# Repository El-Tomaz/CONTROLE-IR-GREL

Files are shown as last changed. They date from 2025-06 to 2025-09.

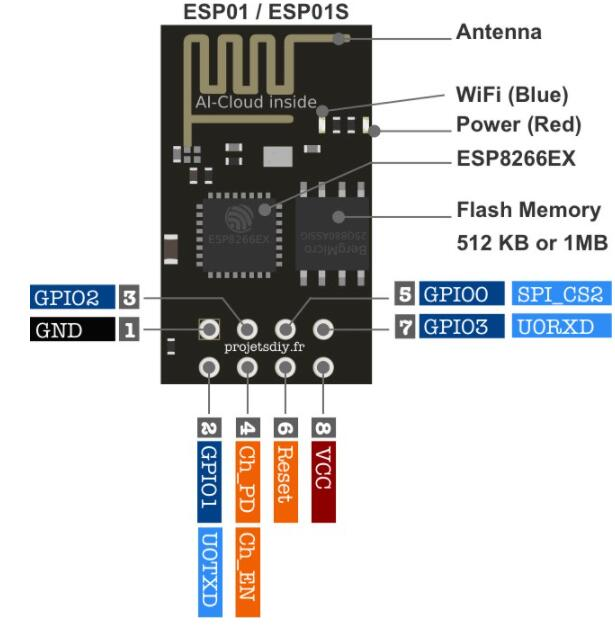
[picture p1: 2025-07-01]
docs/pinout-esp01.png

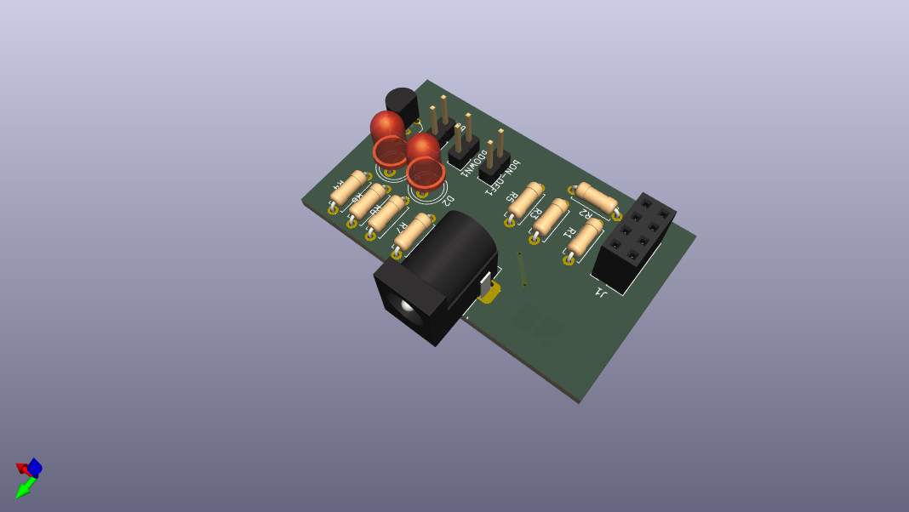
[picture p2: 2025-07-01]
kicad/3d_controle_grel.png

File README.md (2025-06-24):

# CONTROLE IR GREL

Projeto de controle remoto infravermelho (IR) desenvolvido para o laboratório do Grupo de Robótica Educacional Livre (GREL), do IFPB.
O controle é baseado na ESP01. A escolha deste módulo se deu pela necessidade de poucas GPIO's (1 para os LED's IR e 3 para os botões) e custo e tamanho reduzidos.

Projeto utiliza como base a biblioteca: (IR)[]

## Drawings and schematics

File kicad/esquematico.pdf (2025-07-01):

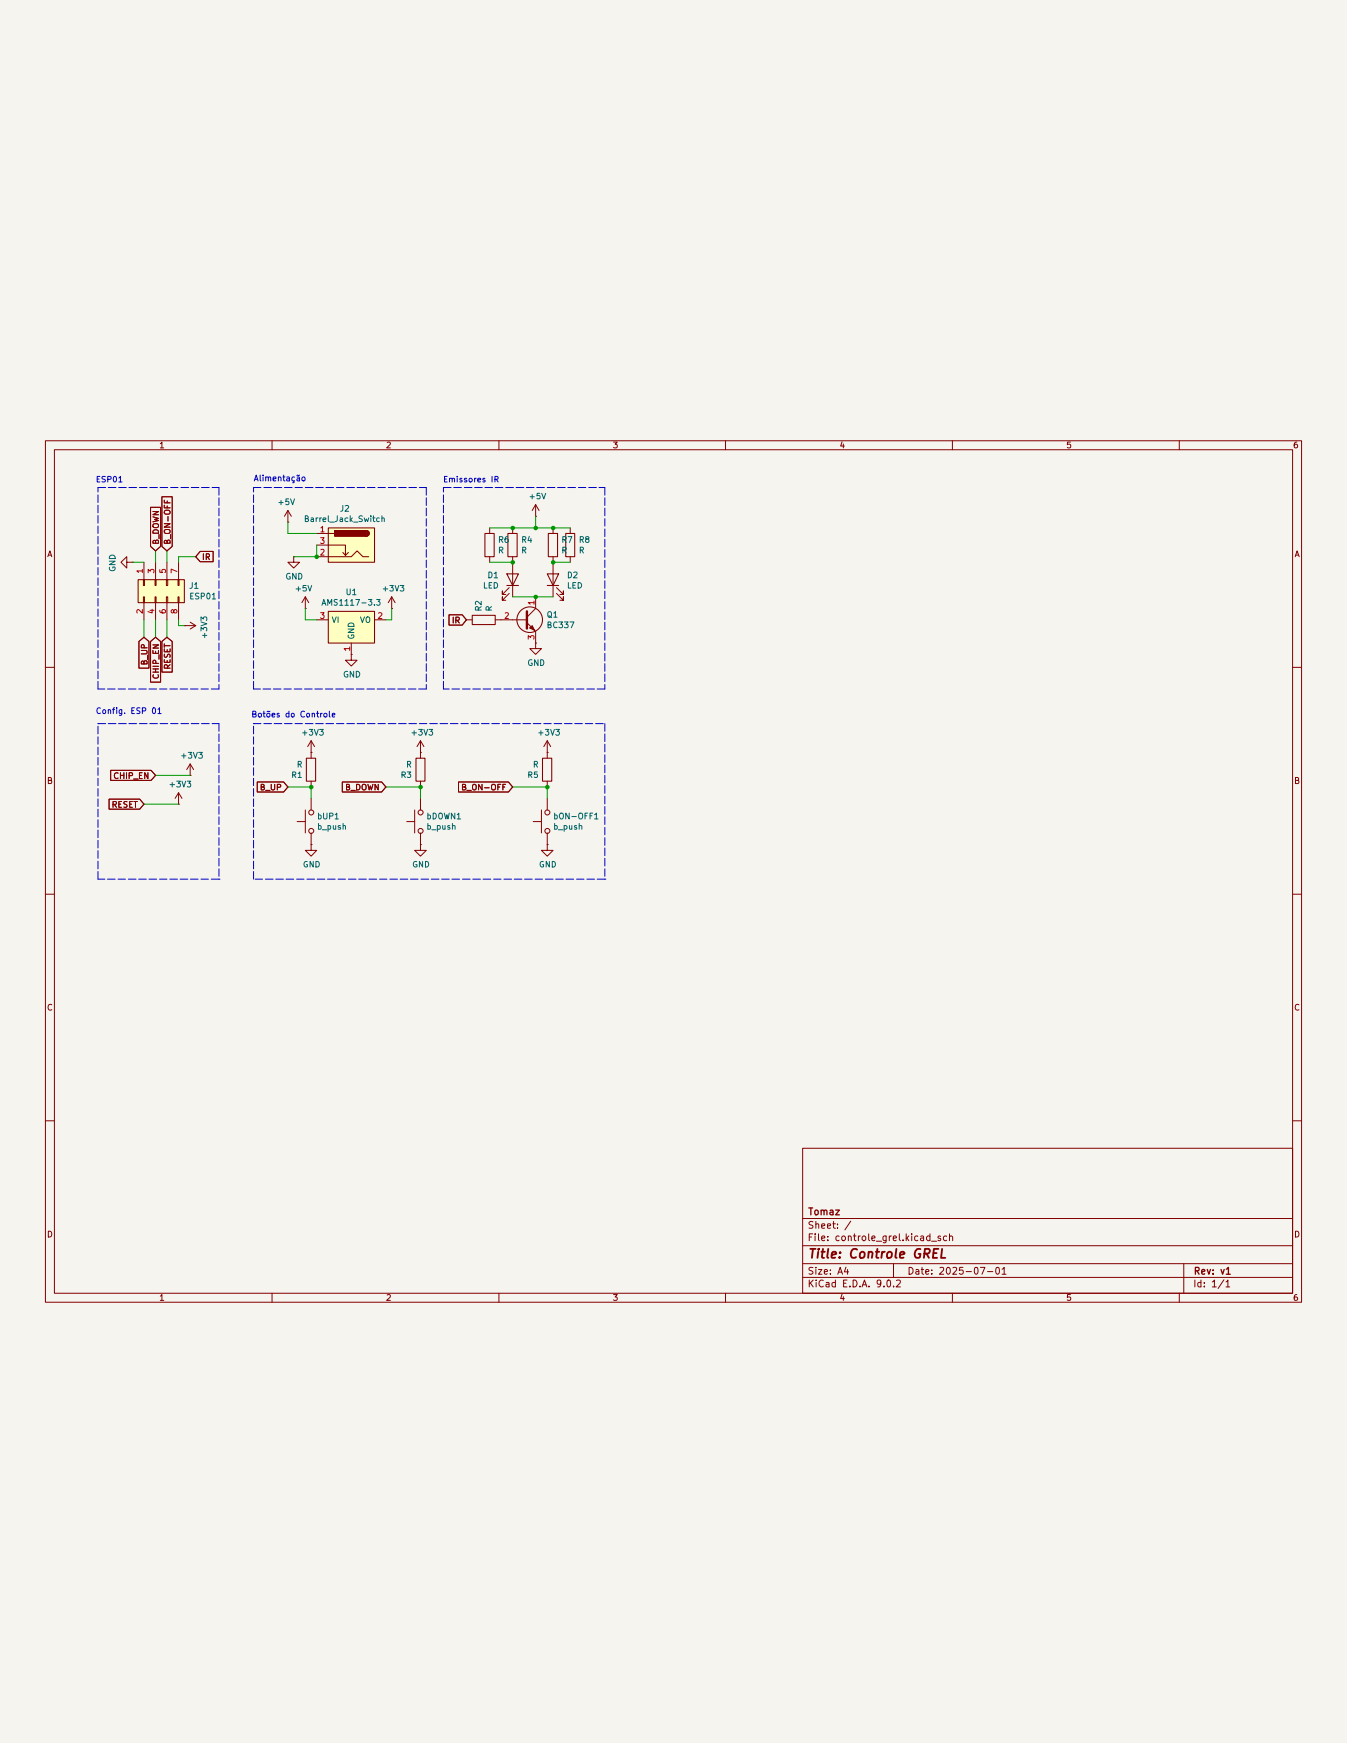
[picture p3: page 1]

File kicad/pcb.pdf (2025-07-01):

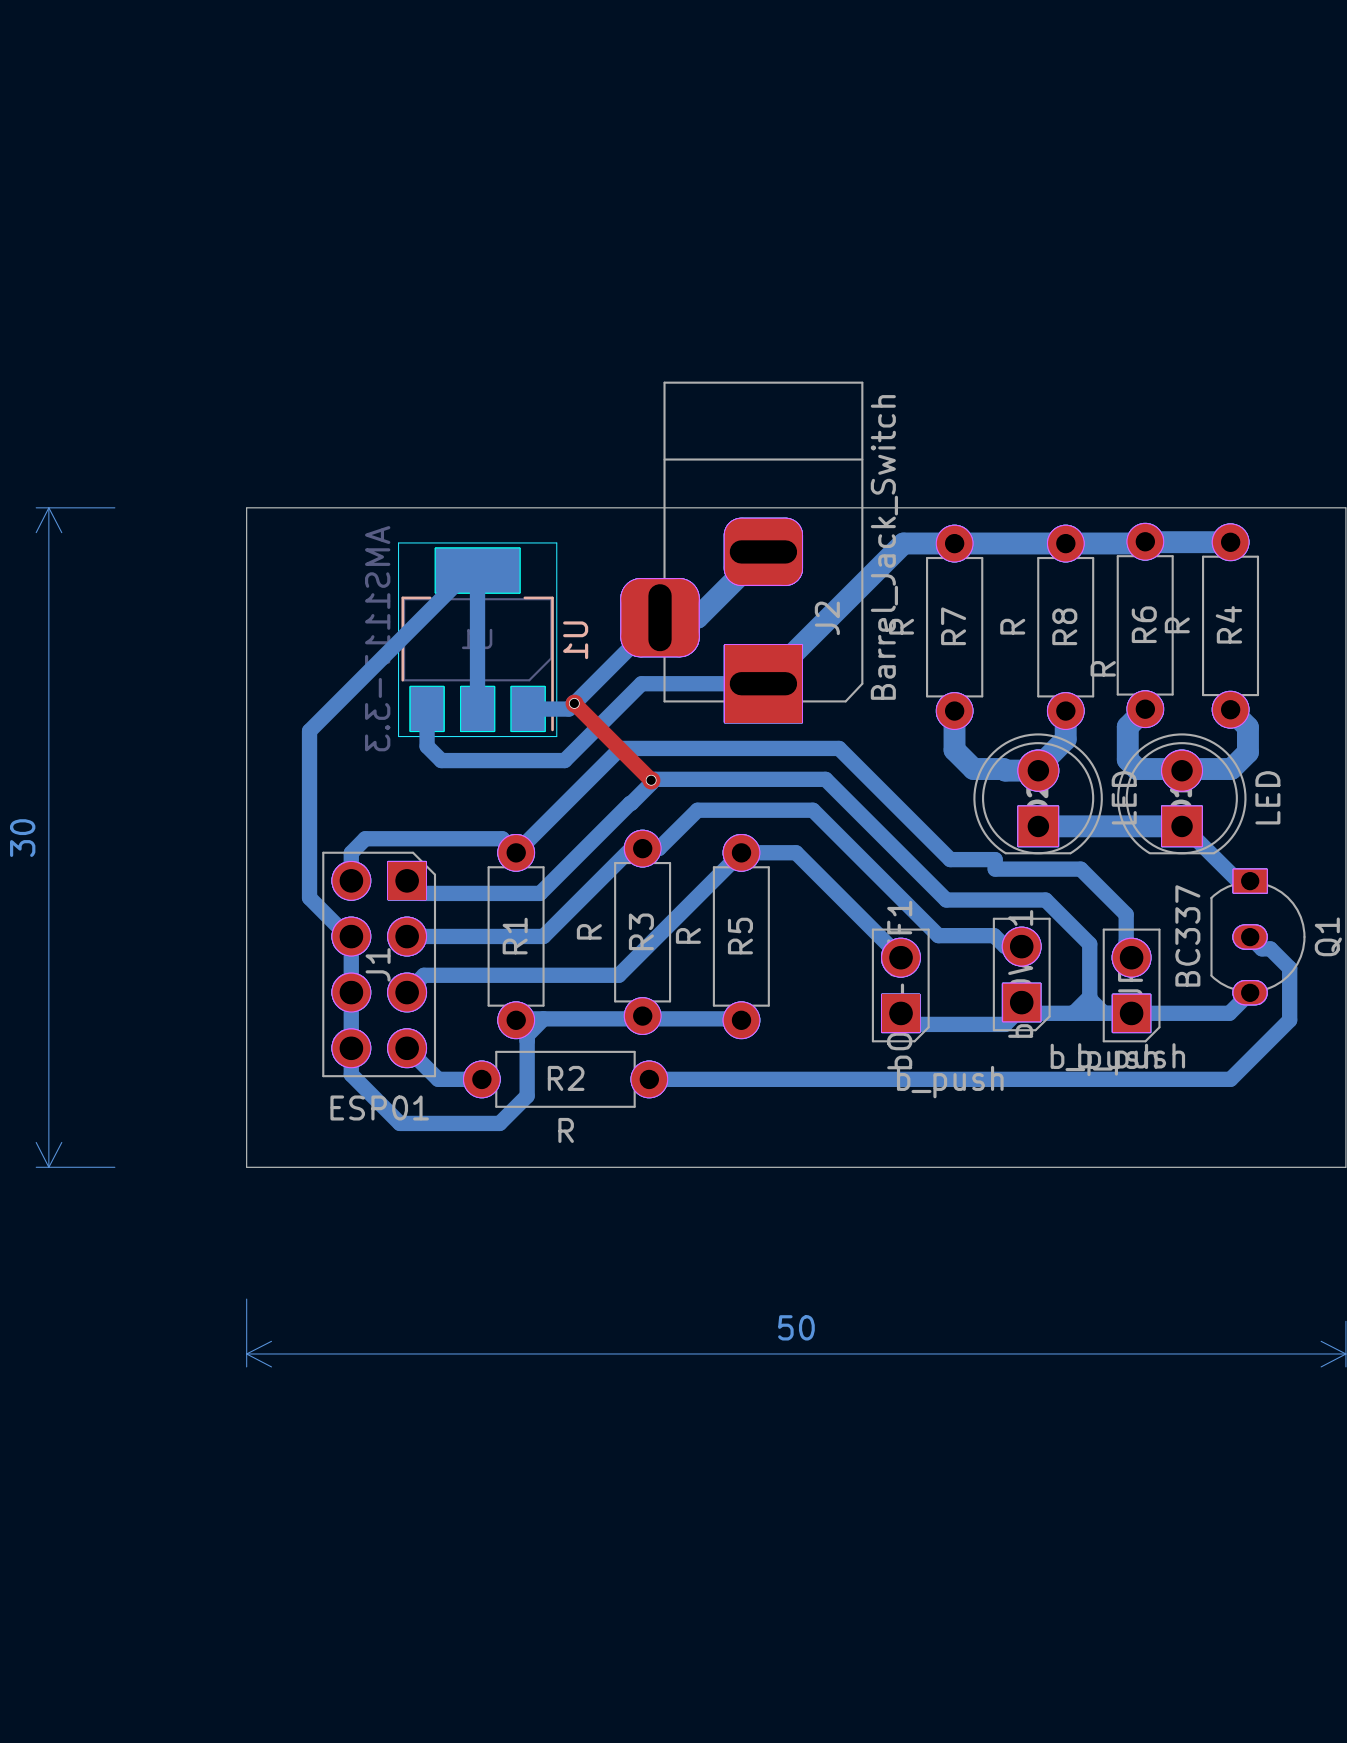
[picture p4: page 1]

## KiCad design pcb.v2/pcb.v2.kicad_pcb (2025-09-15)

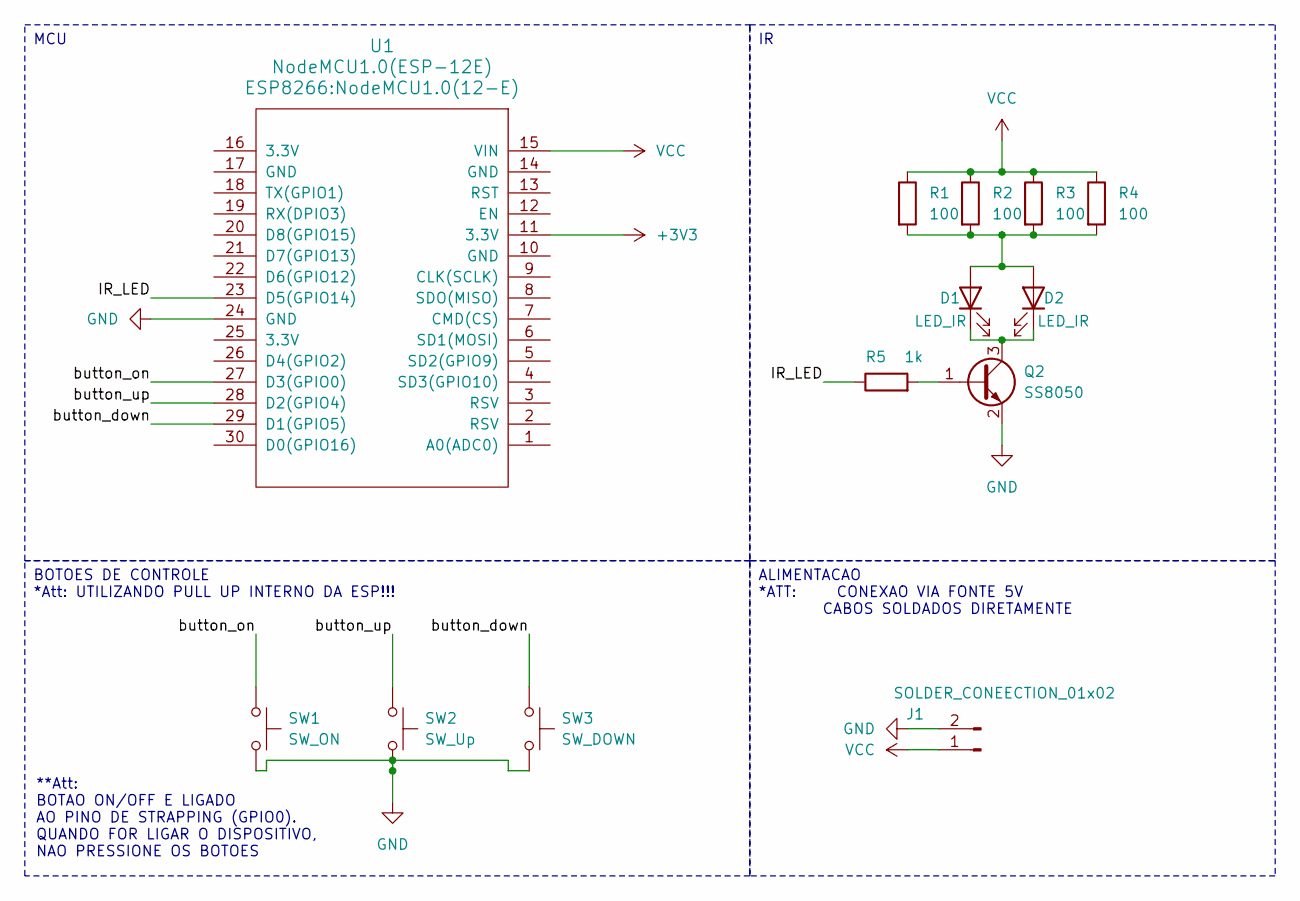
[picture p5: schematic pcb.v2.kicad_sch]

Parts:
D1, D2: LED_IR; LED_D5.0mm_Horizontal_O3.81mm_Z9.0mm
J1: SOLDER_CONEECTION_01x02
Q2: SS8050; SOT-23
R1, R2, R3, R4: 100; R_0805_2012Metric_Pad1.20x1.40mm_HandSolder
R5: 1k; R_0805_2012Metric_Pad1.20x1.40mm_HandSolder
SW1: SW_ON; my_push_button
SW2: SW_Up; my_push_button
SW3: SW_DOWN; my_push_button
U1: NodeMCU1.0(ESP-12E); NodeMCU1.0(12-E)

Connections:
+3V3: U1.11 (3.3V)
/IR_LED: R5.1, U1.23 (D5(GPIO14))
/button_down: SW3.1, U1.29 (D1(GPIO5))
/button_on: SW1.1, U1.27 (D3(GPIO0))
/button_up: SW2.1, U1.28 (D2(GPIO4))
GND: J1.2, Q2.2 (E), SW1.2, SW2.2, SW3.2, U1.24 (GND)
unnamed: D1.2 (A), D2.2 (A), R1.2, R2.2, R3.2, R4.2
unnamed: D1.1 (K), D2.1 (K), Q2.3 (C)
unnamed: Q2.1 (B), R5.2
VCC: J1.1, R1.1, R2.1, R3.1, R4.1, U1.15 (VIN)

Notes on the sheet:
**Att: BOTAO ON/OFF E LIGADO AO PINO DE STRAPPING (GPIO0). QUANDO FOR LIGAR O DISPOSITIVO, NAO PRESSIONE OS BOTOES
MCU
ALIMENTACAO *ATT: CONEXAO VIA FONTE 5V CABOS SOLDADOS DIRETAMENTE
BOTOES DE CONTROLE *Att: UTILIZANDO PULL UP INTERNO DA ESP!!!

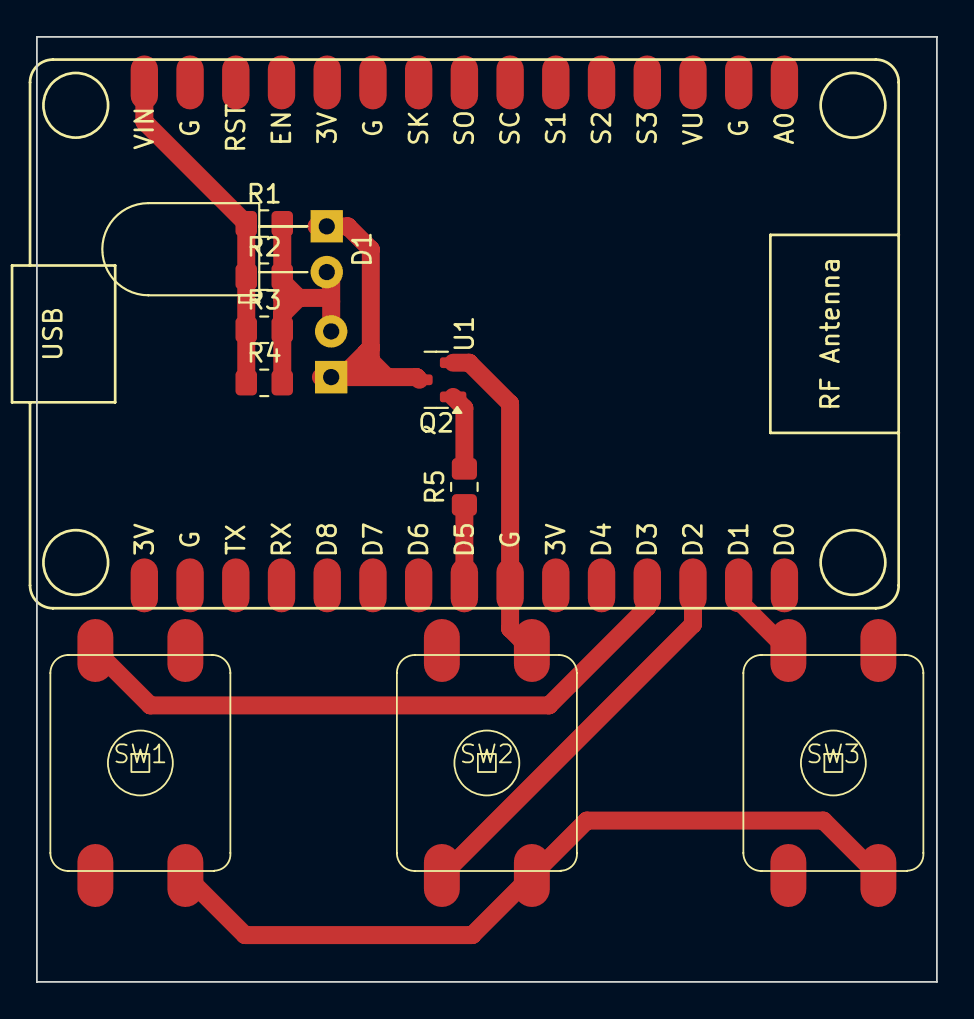
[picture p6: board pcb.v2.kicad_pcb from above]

Board: 2 copper layers, 50.0 x 52.5 mm, 12 parts (1 on the bottom side), 9 nets.

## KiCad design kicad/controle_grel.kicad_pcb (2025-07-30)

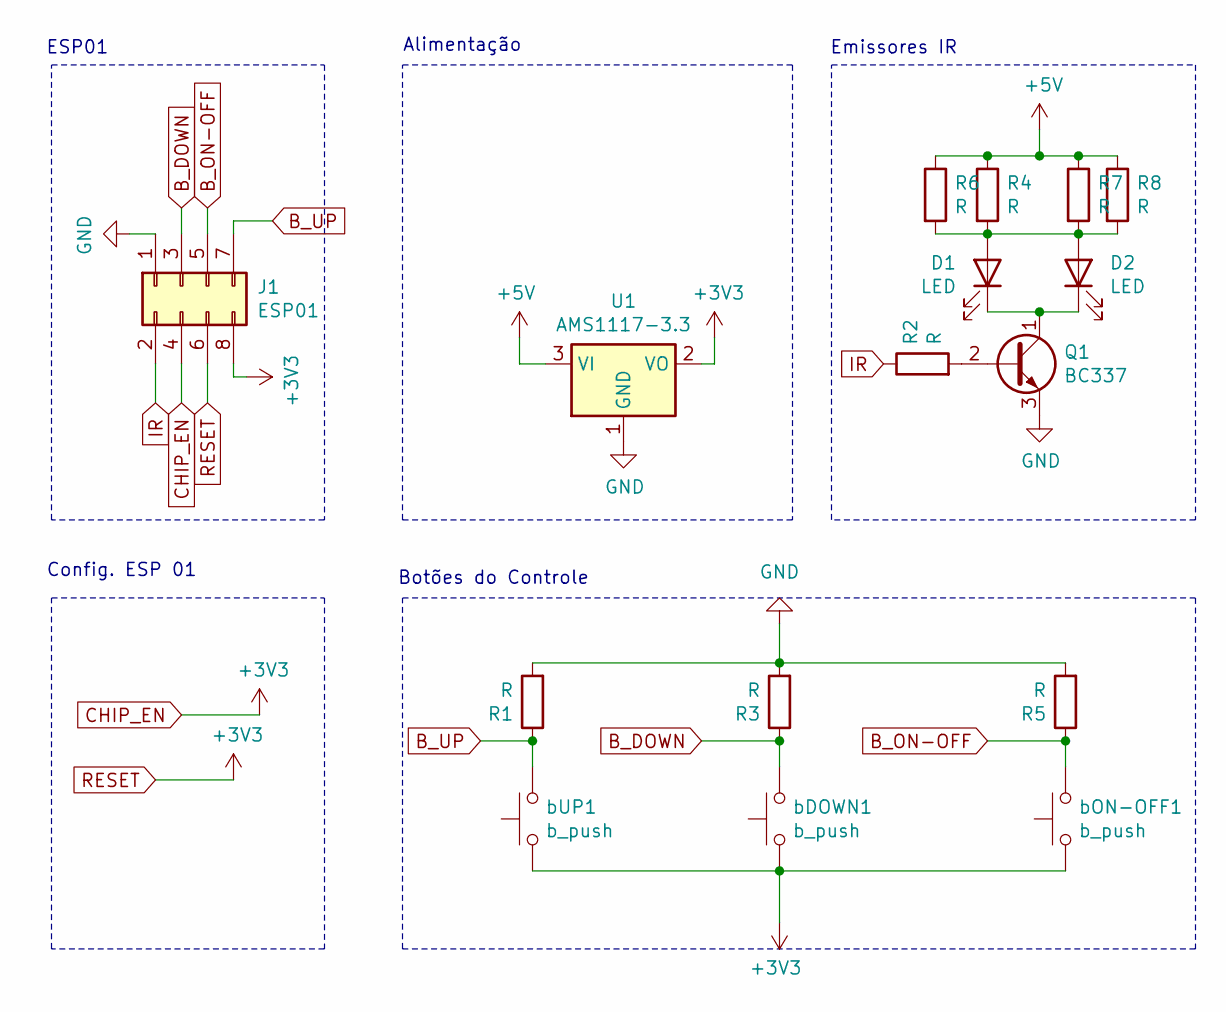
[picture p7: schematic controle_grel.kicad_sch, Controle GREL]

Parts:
D1, D2: LED; LED_D5.0mm
J1: ESP01; PinSocket_2x04_P2.54mm_Vertical_SMD
Q1: BC337; PinHeader_1x03_P2.54mm_Horizontal
R1, R2, R3, R4, R5, R6, R7, R8: R; R_1206_3216Metric
U1: AMS1117-3.3; SOT-223-3_TabPin2
bDOWN1: b_push; PinHeader_1x02_P2.54mm_Vertical
bON-OFF1: b_push; PinHeader_1x02_P2.54mm_Vertical
bUP1: b_push; PinHeader_1x02_P2.54mm_Vertical

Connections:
+5V: R4.1, R6.1, R7.1, R8.1, U1.3 (VI)
B_DOWN: J1.3, R3.1, bDOWN1.2
B_ON-OFF: J1.5, R5.1, bON-OFF1.2
B_UP: J1.7, R1.1, bUP1.2
CHIP_EN: J1.4, J1.6, J1.8, U1.2 (VO), bDOWN1.1, bON-OFF1.1, bUP1.1
GND: J1.1, Q1.3 (E), R1.2, R3.2, R5.2, U1.1 (GND)
IR: J1.2, R2.1
unnamed: D1.2 (A), D2.2 (A), R4.2, R6.2, R7.2, R8.2
unnamed: D1.1 (K), D2.1 (K), Q1.1 (C)
unnamed: Q1.2 (B), R2.2

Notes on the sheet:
Botões do Controle
Config. ESP 01
Emissores IR
ESP01
Alimentação

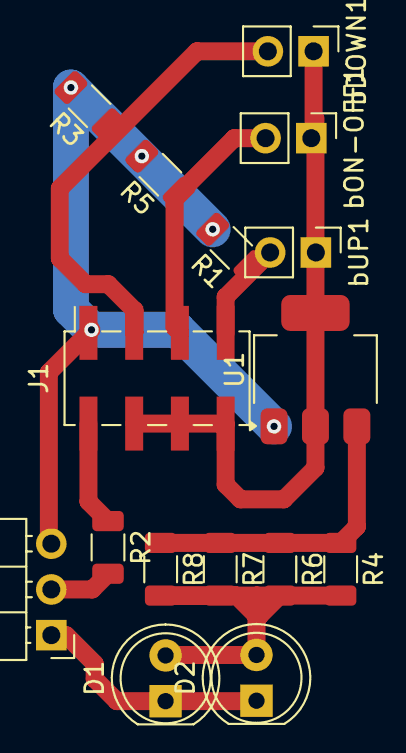
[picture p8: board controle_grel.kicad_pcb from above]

Board: 2 copper layers, 16 parts (0 on the bottom side), 10 nets.

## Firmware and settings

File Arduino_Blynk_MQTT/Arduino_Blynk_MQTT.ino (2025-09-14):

/*
 * SPDX-FileCopyrightText: 2024 Volodymyr Shymanskyy for Blynk Technologies Inc.
 * SPDX-License-Identifier: Apache-2.0
 *
 * The software is provided "as is", without any warranties or guarantees (explicit or implied).
 * This includes no assurances about being fit for any specific purpose.
 */

#include <PubSubClient.h>
#include "NetworkHelpers.h"
#include <WiFiManager.h>


// ========= HARDWARE MAPPING! ===========
const int pButtons[3] = {0,4,5}; //on/off up down
// ATENCAO: os numeros dos pinos na placa esta diferente, conecte fisicamente aos pinos: 3 2 1

// ========= systems constraints
#define MAX_TEMP 24
#define MIN_TEMP 18



// These commands are executed every time
// the device (re)connects to the Blynk Cloud
void mqtt_connected()
{
  // Publish some data
  mqtt.publish("ds/terminal", "Device connected\n");
}

struct {
  int temp = 20;
  bool on = true;
} status;


// Handle incoming datastream changes
// cuida do downlink, pux atualizacoes do blynk para a esp
void mqtt_handler(const String& topic, const String& value)
{
  Serial.print("Got ");       Serial.print(topic);
  Serial.print(", value: ");  Serial.println(value);


  if(topic == "downlink/ds/temp"){
    status.temp = value.toInt();
  }else if(topic == "downlink/ds/on"){
    status.on = value.toInt();
  }

  if (topic == "downlink/ds/terminal") {
    String reply = String("Your command: ") + value;
    mqtt.publish("ds/terminal", reply.c_str());
  }


}

void setup()
{
  WiFi.mode(WIFI_STA);
  WiFi.setAutoReconnect(true);
  WiFi.persistent(true);


  Serial.begin(115200);

  WiFiManager wm;

  bool res = wm.autoConnect("Controle_GREL", "Uma onca calma serena");

  if(!res){
    Serial.println("Falha na conexao :(");
  }else{
    Serial.println("Conectado com sucesso!!");
  }



  // Wait for serial monitor, up to 3 seconds
  while (!Serial && (millis() < 3000)) { delay(10); }
  delay(100);

  systemShowDeviceInfo();
  setClock();

  
  for(int i = 0; i < 3; i++)pinMode(pButtons[i], INPUT_PULLUP);

}



void loop()
{

  bool button_pressed = false; //flag to just send commando to ac and to blynk when button pressed
  static int last_button_state[3] = {1}; // on/off up down
  int actual_button_state[3] = {1};

  for(int i = 0; i < 3;i++){
    actual_button_state[i] = digitalRead(pButtons[i]);
    
    //detectando borda de descida
    if(last_button_state[i] == 1 && actual_button_state[i] == 0){
        
        button_pressed = true;

        switch(i){
          // on/off
          case 0:
            status.on = !status.on;
          break;

          // up
          case 1:
            status.temp++;
          break;

          //down
          case 2:
            status.temp--;
          break;

        }
    }

    last_button_state[i] = actual_button_state[i];  
  }

  // tratando dados (evitar limite de temperatura)
  if(status.temp > MAX_TEMP){
    status.temp = MAX_TEMP;
  }
  else if(status.temp < MIN_TEMP){
    status.temp = MIN_TEMP;
  }

  //enviando commando 
  if(button_pressed){
    Serial.println("BUtton pressed!");
    Serial.println(status.temp);
    Serial.println(status.on);
    // send commando to ac
  }

  // sending info to blynk
  if(button_pressed){
    char temp_payload[3] = "00";
    sprintf(temp_payload, "%d", status.temp);
    mqtt.publish("ds/temp", temp_payload);

    char on_off[2] = "";
    on_off[0] = status.on == true? '1':'0';
    mqtt.publish("ds/on", on_off);

  }


  // todo: caso perca conexao com mqtt -> reenviar dados

  // MQTT connection
  if (!mqtt.connected()) {
    connectMQTT();
  } else {
    bool result = mqtt.loop();
  }

  delay(10);


}

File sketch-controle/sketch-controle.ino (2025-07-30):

#include <Arduino.h>
#include <IRremoteESP8266.h>
#include <IRsend.h>
#include <ir_Midea.h>

//mapa de hardware
#define kIrLed 0

#define bUp 2
#define bDown 3
#define bOnOff 1


IRMideaAC ac(kIrLed);

void setup() {
  Serial.begin(115200);
  //todo: webserver
  ac.begin();
/*
  pinMode(bUp, INPUT);
  pinMode(bDown, INPUT);
  pinMode(bOnOff, INPUT);
*/
}


void loop() {
  Serial.println("Funfando!");

  static bool ligado = false;

  // Set up what we want to send. See ir_Daikin.cpp for all the options.
  ac.on();
 
  // Now send the IR signal.
  ac.send();

  delay(5000);




  // Set up what we want to send. See ir_Daikin.cpp for all the options.
  ac.off();
 
  // Now send the IR signal.
  ac.send();

  delay(5000);
  ligado  = !ligado;
}

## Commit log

2025-06-24 Adicionado arquivo kicad!!!
    [controle_grel.kicad_pcb, controle_grel.kicad_sch]
2025-06-24 pcb: corrijindo pinagem esp01 e aumentando espaçamento
    [controle_grel.kicad_pcb]
2025-06-24 firmware: adicionado primeiro sketch de teste
    docs: add reame!
2025-07-01 pcb: corrigido lado do ams1117 (colocando no botton)
    [controle_grel.kicad_pcb, controle_grel.kicad_sch]
2025-07-30 Consegui corroer a plaquinhaaaa
    [controle_grel.kicad_pcb, controle_grel.kicad_sch]
2025-09-14 dev: botoes implementados, uplink para blynk mqtt implementado
    todo: downlink do blynk mqtt (o controle local terá prioridade)
    todo: pcb
    todo: case 3d
2025-09-14 dev: downlink implementado, a esp consegue atualizar blynk e puxar dados de la tbm
2025-09-15 pcb: criada pcb com nodemcu todo: modelo da case no freecad todo: pcb apenas com modulo 12E
    note: testando transistores sot23 (acredito que dao conta da potencia do disparo IR)
    [pcb.v2.kicad_pcb, pcb.v2.kicad_sch]
